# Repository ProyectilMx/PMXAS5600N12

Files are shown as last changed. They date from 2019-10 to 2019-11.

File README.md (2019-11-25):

PMXAS5600N12
Encoder Absoluto basado en el integrado AS5600 con 12 neopixels, configurable a través 
de COM Serial 9600 baudios

PMXAS5600N12 version 1.0 - 25/11/2019
PROYECTIL MX - HAZLO REAL

Modulo de Medicion Angular Absoluta Magnetica, programable mediante comandos UART

Esta provisto de un sensor de la marca AMS, el AS5600, que es un sensor
magnetico rotatorio de posicion con una resolucion de 12 bits, para un
rango por hardware de 4095°, el programa provee de otros 4095° para un
rango maximo total de -4095 a 4095°. Por defecto, el sitema viene en un
rango de 0 a 360°.

La placa contiene un microcontrolador maestro, basado en un ATSAMD21E18
de 32 bits, para realizar todas las mediciones y calculos a una velocidad 
de 96MHz, con este rapido sistema se logran obtener mediciones de hasta
6000RPM con 100% de presicion, tanto en revoluciones como en angulo.
La placa tambien consta de varios pines de salida para obtener funcionalidades
diversas:

PA27 - PA18:
Salidas programables en rangos angulares, programables en nivel alto o
bajo dentro de los mismos. Por defecto vienen con los siguientes limites:
PA27 -> de 0° a 90°
PA22 -> de 90° a 180°
PA19 -> de 180° a 270°
PA18 -> de 270° a 360°.
Con estas salidas se puede emular un registro de corrimiento de 4 bits o
activar subsistemas dentro de cierto angulo.

PA14, PA09:
Salidas que generan un pulso de 10us con cada revolucion. 
PA14 -> genera un pulso en el sentido de las manecillas del reloj. 
PA09 -> genera un pulso en el sentido contrario a las manecillas del reloj.

PA05:
Genera una señal PWM con una frecuencia variable entre 1 KHz y 4MHz, con un
ciclo de trabajo configurable entre 0 - 100%, dependiendo de la posicion angular.

PA02:
Genera una señal analogica de 10 bits, de entre 0 y 3.3v aproximadamente, 
dependiendo de la posicion angular.

PA07:
Se puede configurar para activarse dentro de un rango determinado de vueltas. 
Por ejemplo, si se configura que PA07 este en HIGH cuando se este entre 
0 y 500 vueltas, el pulso cambiara a LOW si el numero de vueltas esta fuera 
de ese intervalo.

PA06:
Se puede configurar para que al llegar a un multiplo de vueltas, por ejemplo, 15,  se de 
un pulso de un tiempo configurable en HIGH, por lo tanto este pulso sucederia en 0, 15,
30, 45, 60, 75.... vueltas.

PA04, PA03, PA01, PA00.
Salidas/Entradas: 
Estos pines solamente pueden ser entradas o salidas digitales.

Las funciones de la placa que se encuentran disponibles para el usuraio son:

void pmxas5600n12_configure(void);    - Configura todos los perifericos de la placa
void pmxas5600n12_exe(void);          - Ejecuta todas las acciones de control pertinentes a la placa

Se pueden utilizar las siguiente variables en el programa principal para interactuar con la placa:
 
user_turn       -  Reporta el numero de vueltas actual
user_angle      -  Reporta el angulo actual en 12 bits (0 - 4095)

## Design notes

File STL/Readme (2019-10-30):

Estos archivos son para imprimir en 3D un Knob compatible con la placa, el cual albergará un Imán de neodimio de 7mm de diámetro, por 3mm de espesor.

Es importante que el imán quede con los campos magnéticos perpendiculades a la placa, puesto que si queda alineado con ella, al rotar el imán, en realidad los campos seguirían estando igualemente orientados.

Knob-base.STL
Esta es la base atornillable a la PCB, por medio de 2 tornillos M3x6mm. Cuenta con espacio para un balero 624ZZ en su interior, comunmente utilizados para armar impresoras 3D.

Knob-giratorio.STL
Esta pieza alberga el imán de neodimio y cuenta con la forma para motar una neumático de llanta tipo Pololu de 30mm de diámetro.

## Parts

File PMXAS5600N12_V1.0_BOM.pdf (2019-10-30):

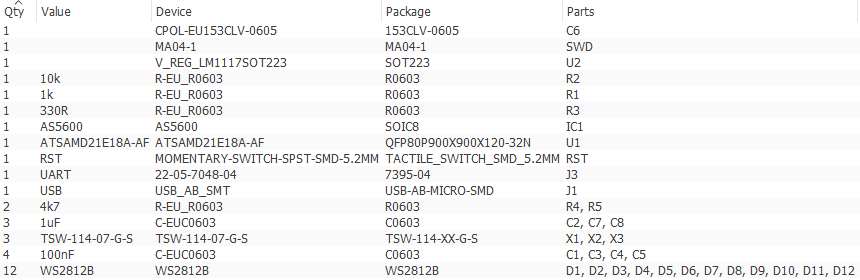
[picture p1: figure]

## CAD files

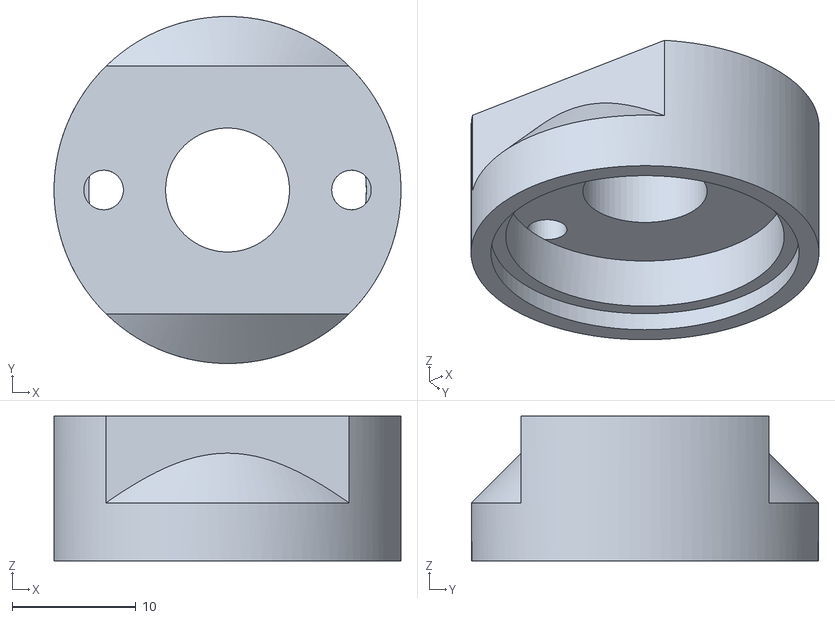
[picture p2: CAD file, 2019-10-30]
STL/Knob-base.stl
28.0 x 28.0 x 11.7

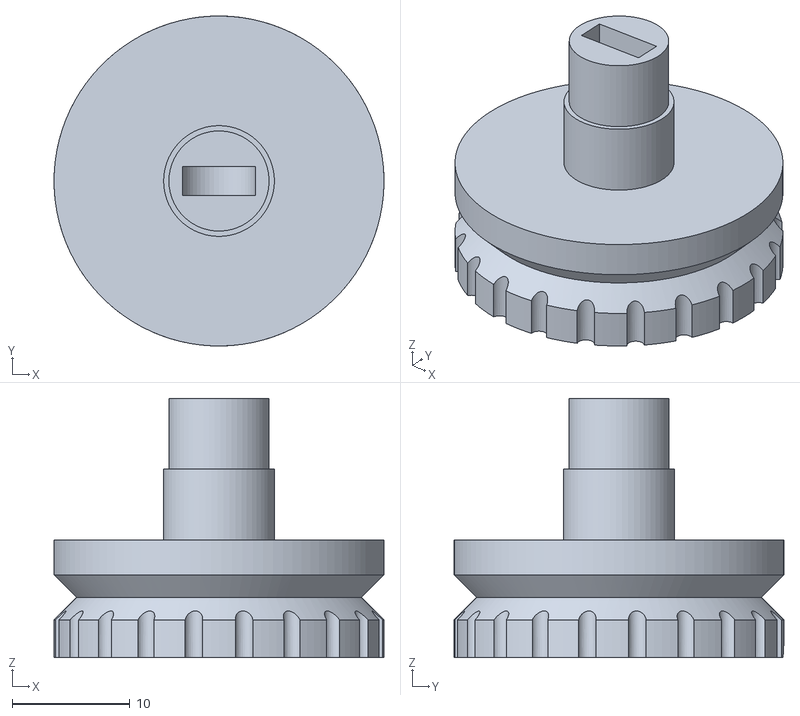
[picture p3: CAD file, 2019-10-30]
STL/Knob-giratorio.stl
28.0 x 28.0 x 22.0

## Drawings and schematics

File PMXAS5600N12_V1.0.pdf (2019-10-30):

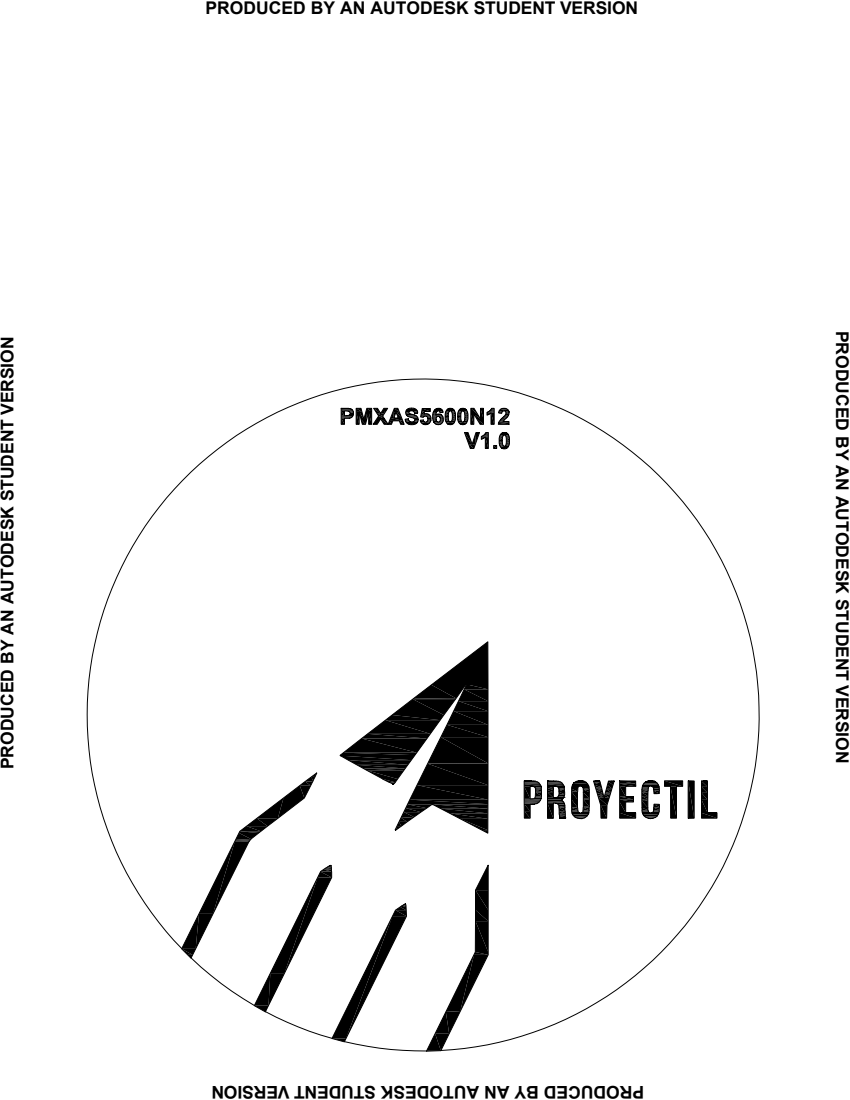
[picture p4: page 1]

PRODUCED BY AN AUTODESK STUDENT VERSION

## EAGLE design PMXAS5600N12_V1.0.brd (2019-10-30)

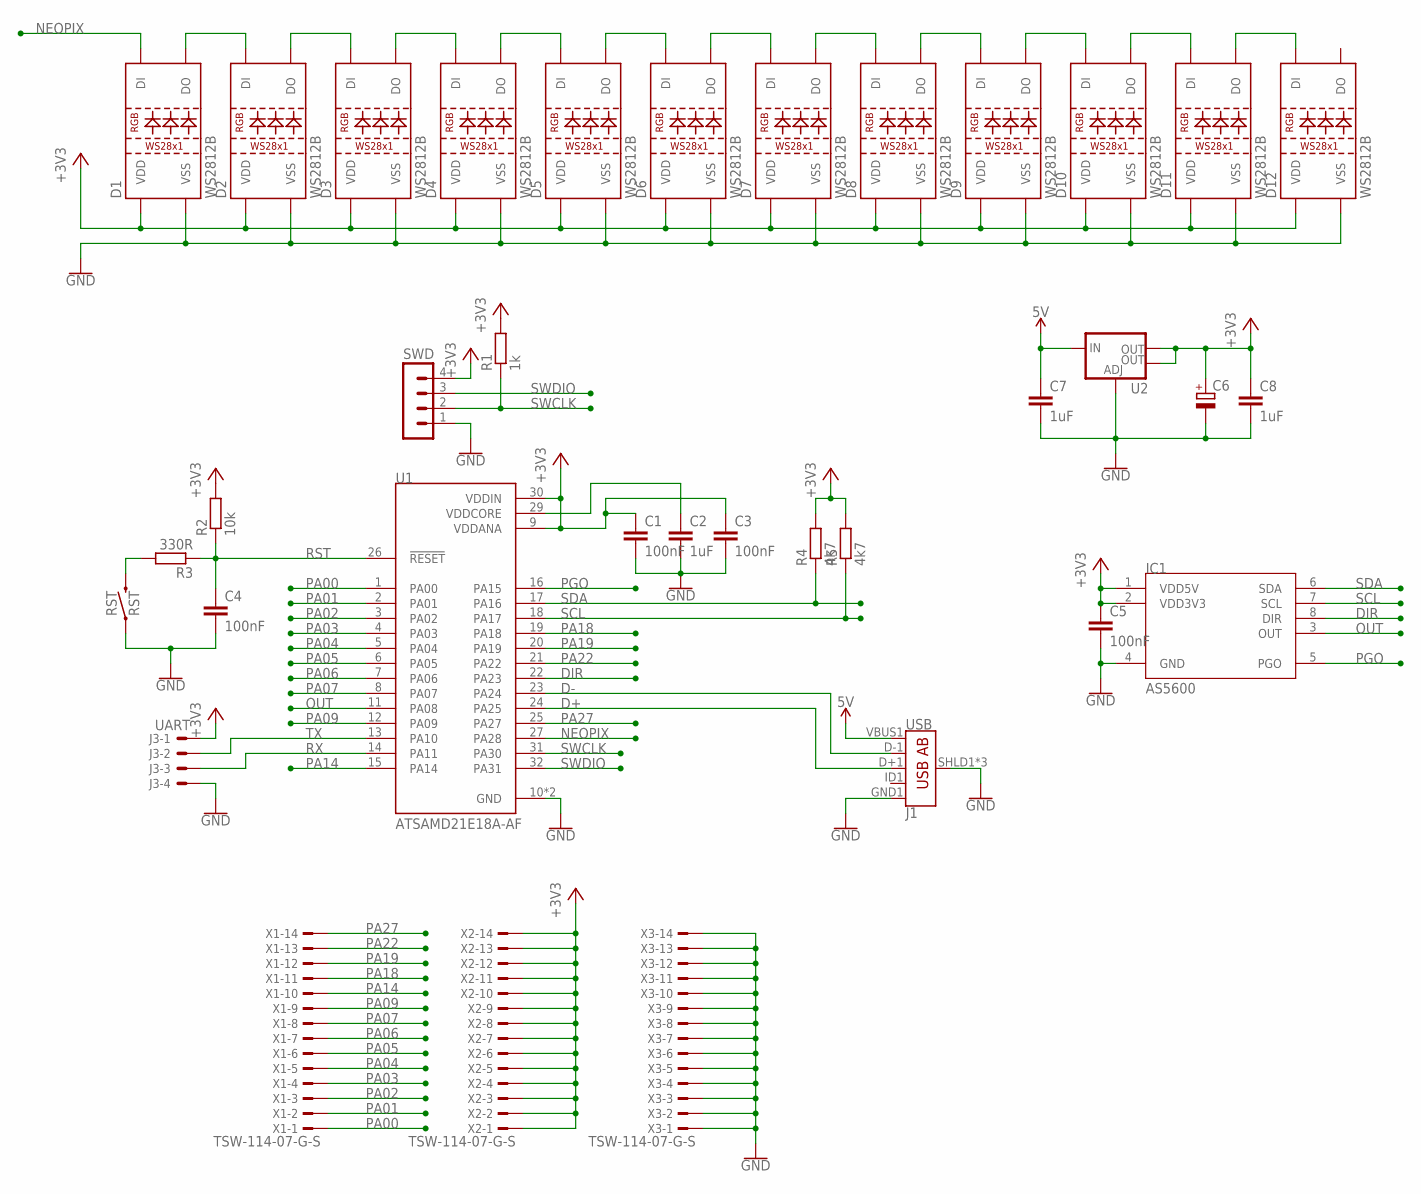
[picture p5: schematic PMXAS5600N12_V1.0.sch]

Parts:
C1, C3, C4, C5: 100nF; C0603
C2, C7, C8: 1uF; C0603
C6: CPOL-EU153CLV-0605; 153CLV-0605
D1, D2, D3, D4, D5, D6, D7, D8, D9, D10, D11, D12: WS2812B
IC1: AS5600; SOIC8
J1: USB; USB-AB-MICRO-SMD
J3: UART; 7395-04
R1: 1k; R0603
R2: 10k; R0603
R3: 330R; R0603
R4, R5: 4k7; R0603
RST: RST; TACTILE_SWITCH_SMD_5.2MM
SWD: MA04-1
U1: ATSAMD21E18A-AF; QFP80P900X900X120-32N
U2: V_REG_LM1117SOT223; SOT223
X1, X2, X3: TSW-114-07-G-S; TSW-114-XX-G-S

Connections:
5V: C7.1, J1.VBUS1 (VBUS), U2.3 (IN)
+3V3: C1.1, C3.1, C5.1, C6.+, C8.1, D1.1 (VDD), D2.1 (VDD), D3.1 (VDD), D4.1 (VDD), D5.1 (VDD), D6.1 (VDD), D7.1 (VDD), D8.1 (VDD), D9.1 (VDD), D10.1 (VDD), D11.1 (VDD), D12.1 (VDD), IC1.1 (VDD5V), IC1.2 (VDD3V3), J3.1, R1.2, R2.2, R4.2, R5.2, SWD.4, U1.9 (VDDANA), U1.30 (VDDIN), U2.2 (OUT), U2.4 (OUT), X2.1, X2.2, X2.3, X2.4, X2.5, X2.6, X2.7, X2.8, X2.9, X2.10, X2.11, X2.12, X2.13, X2.14
D+: J1.D+1 (D+), U1.24 (PA25)
D-: J1.D-1 (D-), U1.23 (PA24)
DIR: IC1.8 (DIR), U1.22 (PA23)
GND: C1.2, C2.2, C3.2, C4.2, C5.2, C6.-, C7.2, C8.2, D1.3 (VSS), D2.3 (VSS), D3.3 (VSS), D4.3 (VSS), D5.3 (VSS), D6.3 (VSS), D7.3 (VSS), D8.3 (VSS), D9.3 (VSS), D10.3 (VSS), D11.3 (VSS), D12.3 (VSS), IC1.4 (GND), J1.GND1 (GND), J1.SHLD1 (SHIELD), J1.SHLD2 (SHIELD), J1.SHLD3 (SHIELD), J3.4, RST.1, SWD.1, U1.10 (GND), U1.28 (GND), U2.1 (ADJ), X3.1, X3.2, X3.3, X3.4, X3.5, X3.6, X3.7, X3.8, X3.9, X3.10, X3.11, X3.12, X3.13, X3.14
unnamed: D1.2 (DO), D2.4 (DI)
unnamed: D2.2 (DO), D3.4 (DI)
unnamed: D3.2 (DO), D4.4 (DI)
unnamed: D4.2 (DO), D5.4 (DI)
unnamed: D5.2 (DO), D6.4 (DI)
unnamed: D6.2 (DO), D7.4 (DI)
unnamed: D7.2 (DO), D8.4 (DI)
unnamed: D8.2 (DO), D9.4 (DI)
unnamed: D9.2 (DO), D10.4 (DI)
unnamed: D10.2 (DO), D11.4 (DI)
unnamed: D11.2 (DO), D12.4 (DI)
unnamed: R3.2, RST.3 (2)
NEOPIX: D1.4 (DI), U1.27 (PA28)
OUT: IC1.3 (OUT), U1.11 (PA08)
PA00: U1.1 (PA00), X1.1
PA01: U1.2 (PA01), X1.2
PA02: U1.3 (PA02), X1.3
PA03: U1.4 (PA03), X1.4
PA04: U1.5 (PA04), X1.5
PA05: U1.6 (PA05), X1.6
PA06: U1.7 (PA06), X1.7
PA07: U1.8 (PA07), X1.8
PA09: U1.12 (PA09), X1.9
PA14: U1.15 (PA14), X1.10
PA18: U1.19 (PA18), X1.11
PA19: U1.20 (PA19), X1.12
PA22: U1.21 (PA22), X1.13
PA27: U1.25 (PA27), X1.14
PGO: IC1.5 (PGO), U1.16 (PA15)
RST: C4.1, R2.1, R3.1, U1.26 (!RESET)
RX: J3.3, U1.14 (PA11)
SCL: IC1.7 (SCL), R5.1, U1.18 (PA17)
SDA: IC1.6 (SDA), R4.1, U1.17 (PA16)
SWCLK: R1.1, SWD.2, U1.31 (PA30)
SWDIO: SWD.3, U1.32 (PA31)
TX: J3.2, U1.13 (PA10)
VDDCORE: C2.1, U1.29 (VDDCORE)

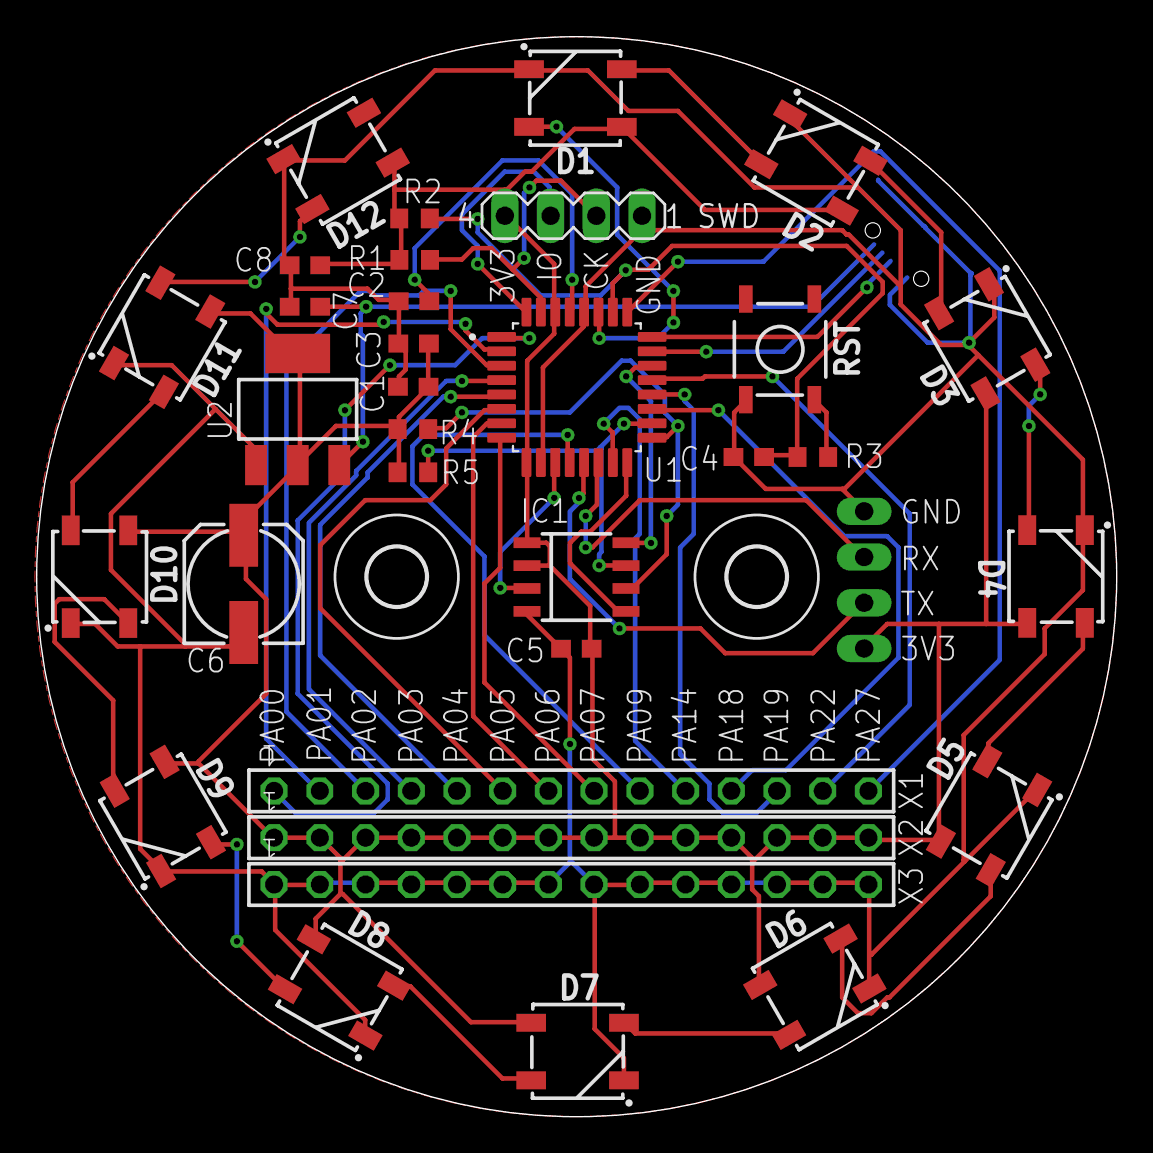
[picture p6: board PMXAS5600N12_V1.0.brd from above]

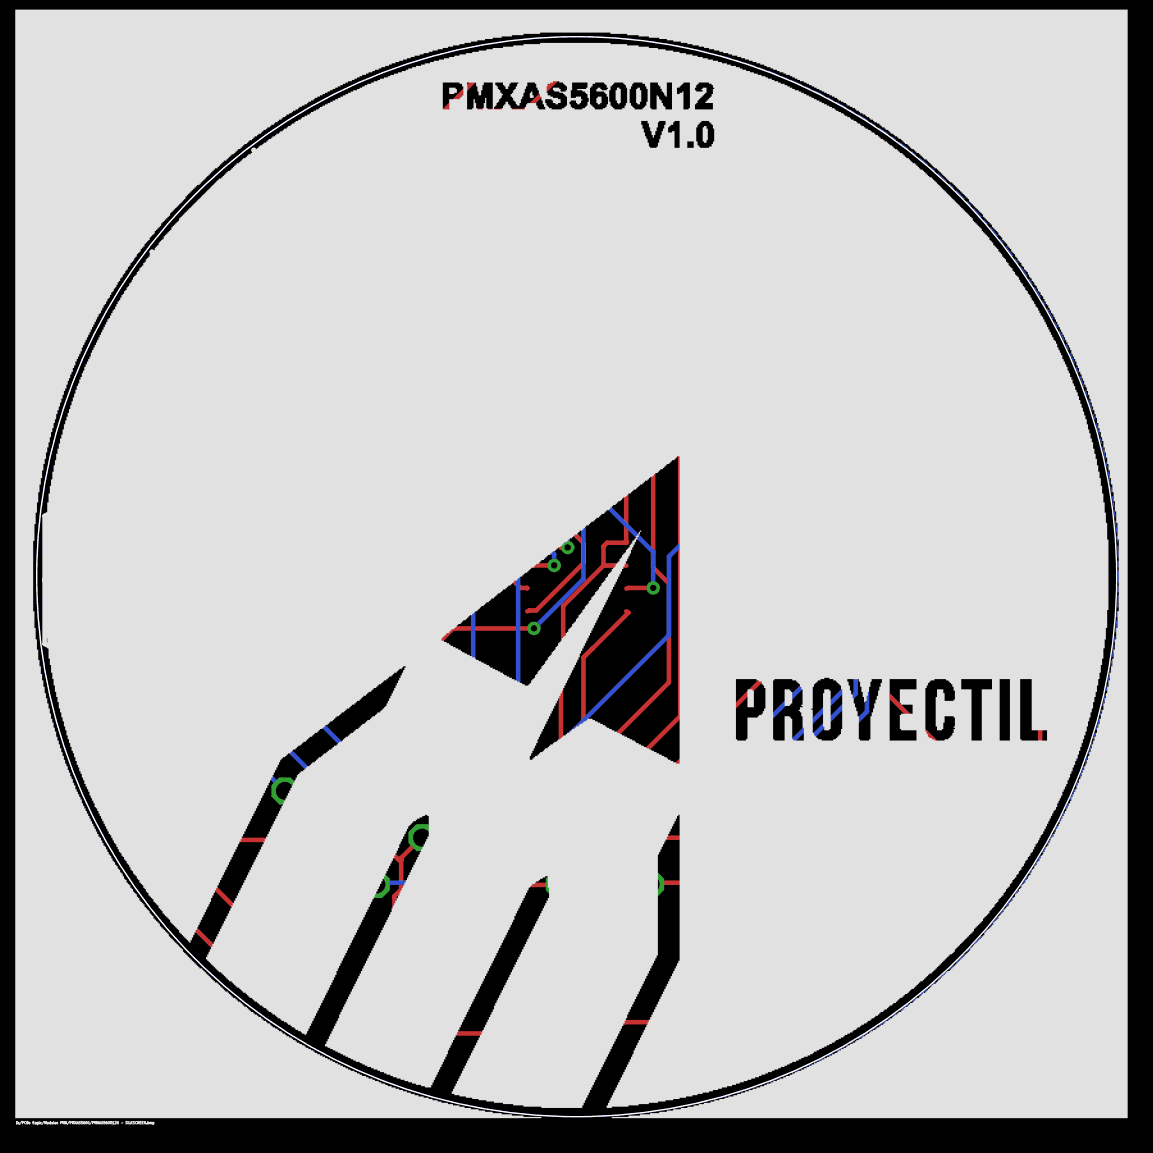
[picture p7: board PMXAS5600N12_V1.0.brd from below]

Board: 2 copper layers, 60.0 x 60.0 mm, 37 parts (2 on the bottom side), 43 nets.

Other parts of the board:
U$1, U$2: 3,2

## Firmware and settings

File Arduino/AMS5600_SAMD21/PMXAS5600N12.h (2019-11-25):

#include <Arduino.h>         
#include <Wire.h>
#include <AMS_5600.h> 
#include <stdio.h>
#include <string.h>
#include <ctype.h>
#include <FlashStorage.h>
#include <Adafruit_NeoPixel.h>

#define NEOP      9   // pin de neopixel
#define PIX_NUM   12  // numero de neopixels
// Crea instancia e inicializa Neopixels
Adafruit_NeoPixel pixels = Adafruit_NeoPixel(PIX_NUM, NEOP, NEO_GRB + NEO_KHZ800);

// Crea instancia para el sensor
AMS_5600 ams;

#define OSC_FREQ        48000000
#define I2CSPEED        1000000

#define USB             1
#define SERIAL          0

#define ONE_THIRD_FULL_ANGLE    1365
#define TWO_THIRD_FULL_ANGLE    2730
#define PIX_PORTION     342
#define CCW             0
#define CW              1
#define NO_ACK          0
#define MIN_ACK         1
#define FULL_ACK        2
#define CALL            0
#define CHANGE          1
#define FLUID           2
#define DUTY            0
#define FREQUENCY       1  

#define VERSION         1
#define ANGLEMAX        2
#define ANGLEMIN        3
#define ANGLEFULL       4
#define ANGLE           5
#define DIRECTION       6
#define TURN            7
#define PA27MIN_ANGLE   8
#define PA27MAX_ANGLE   9
#define PA22MIN_ANGLE   10
#define PA22MAX_ANGLE   11
#define PA19MIN_ANGLE   12
#define PA19MAX_ANGLE   13
#define PA18MIN_ANGLE   14
#define PA18MAX_ANGLE   15
#define PA07MIN_TURN    16
#define PA07MAX_TURN    17
#define PA06MULTIPLE    18
#define BAUD            19

#define RED             1
#define GREEN           2
#define BLUE            3
#define YELLOW          4
#define MAGENTA         5
#define CYAN            6
#define WHITE           7

#define SINGLE          1
#define RISING          2
#define FALLING         3

FlashStorage(ADD_ack_level, int);
FlashStorage(ADD_flag_angleFluid, short);
FlashStorage(ADD_flag_turnFluid, short);
FlashStorage(ADD_updateMode, short);
FlashStorage(ADD_max_angle, int);
FlashStorage(ADD_min_angle, int);
FlashStorage(ADD_turn, long long);
FlashStorage(ADD_turnUpdate, short);
FlashStorage(ADD_direction, short);
FlashStorage(ADD_angleContinue, short);
FlashStorage(ADD_angleUpdate, short);
FlashStorage(ADD_turnContinue, short);
FlashStorage(ADD_pa27_min_angle, int);
FlashStorage(ADD_pa27_max_angle, int);
FlashStorage(ADD_pa27_enable, int);
FlashStorage(ADD_pa27_logic, short);
FlashStorage(ADD_pa22_min_angle, int);
FlashStorage(ADD_pa22_max_angle, int);
FlashStorage(ADD_pa22_enable, int);
FlashStorage(ADD_pa22_logic, short);
FlashStorage(ADD_pa19_min_angle, int);
FlashStorage(ADD_pa19_max_angle, int);
FlashStorage(ADD_pa19_enable, int);
FlashStorage(ADD_pa19_logic, short);
FlashStorage(ADD_pa18_min_angle, int);
FlashStorage(ADD_pa18_max_angle, int);
FlashStorage(ADD_pa18_enable, int);
FlashStorage(ADD_pa18_logic, short);
FlashStorage(ADD_pa07_min_turn, int);
FlashStorage(ADD_pa07_max_turn, int);
FlashStorage(ADD_pa07_enable, int);
FlashStorage(ADD_pa07_logic, short);
FlashStorage(ADD_pa06_turn_mult, int);
FlashStorage(ADD_pa06_enable, int);
FlashStorage(ADD_pa06_logic, short);
FlashStorage(ADD_pa06_pulse_duration, int);

FlashStorage(ADD_baud, long);
FlashStorage(ADD_ackDelay, unsigned int);
FlashStorage(ADD_color_bright, unsigned int);
FlashStorage(ADD_pixel_enable, short);
FlashStorage(ADD_pixel_color, int);
FlashStorage(ADD_pixel_effect, int);
FlashStorage(ADD_turn_pulse_duration, int);

// Variables globales
bool input_channel;
int max_angle = 360;
int min_angle = 0;
const long long min_turn = -2147483648;
const long long max_turn = 2147483647;
int full_angle = max_angle - min_angle;
int ack_level = FULL_ACK;
int raw_angle;
int angle;
int raw_new_angle;
int new_angle;
int user_angle;
int user_turn;
int raw_old_angle;
int old_angle;
int ackDelay = 1000;
int requestValue = NULL;
int color_bright = 50;
int pixel_color = RED;
int pixel_effect = SINGLE;
int turn_pulse_duration = 1000;   // uS
int pa27_min_angle = 0;
int pa27_max_angle = 90;
int pa22_min_angle = 90;
int pa22_max_angle = 180;
int pa19_min_angle = 180;
int pa19_max_angle = 270;
int pa18_min_angle = 270;
int pa18_max_angle = 360;
int pa07_min_turn = 0;
int pa07_max_turn = 10;
int pa06_pulse_duration = 100;    // uS
long long pa06_turn_mult = 10;  // multiplo de vueltas para dar un pulso en PA06
int updateMode = CALL;
int ind[5] = {0,0,0,0,0}; // posiciones de los comandos

long baud = 9600;
long long turn = 0;
long long new_turn;
long long old_turn;

short flag_newCommand = false;
short flag_newTurn = false;
short flag_turnChanged = false;
short flag_angleFluid = true;
short flag_angleChanged = false;
short flag_turnFluid = true;
short flag_direction = CW;
short flag_error_syntax = false;
short flag_error_range = false;
short flag_error_void = false;
short flag_pa27_level = HIGH;
short flag_pa22_level = HIGH;
short flag_pa19_level = HIGH;
short flag_pa18_level = HIGH;
short flag_pa07_level = HIGH;
short flag_pa06_level = HIGH;
short pa27_enable = true;
short pa27_logic = true;
short pa22_enable = true;
short pa22_logic = true;
short pa19_enable = true;
short pa19_logic = true;
short pa18_enable = true;
short pa18_logic = true;
short pa07_enable = true;
short pa07_logic = true;
short pa06_enable = true;
short pa06_logic = true;
short pixel_enable = true;


String firmwareVersion = "PMXAS5600N12 - Version 1.0 - 28/02/2019";
String readString; // string introducido por usuario
String subCom[6] = {"","","","","",""}; // String para cada subcomando
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

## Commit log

2019-11-01 Add files via upload
    En esta carpeta se encuentran los archivos Variant para una configuración de Arduino más avanzada
    [PMXAS5600N12.cfg]
2019-11-25 Se lanza la versión publica de PMXAS5600N12
    - Se corrigieron algunos bugs
    - Se implementó nueva funcionalidad en los pines PA06 y PA07
    - Se bajó la velocidad por defecto a 9600 bauds.
    - Se habilitó el Serial1 para poder comunicarse con otra placa.
    [AMS5600_SAMD21.ino, PMXAS5600N12.h]
2019-11-25 Actializacion de Readme con nuevas funciones
2019-11-25 Corrección de errores Ortográficos
2019-11-25 Cambios en la descripción de la placa PMXAS5600N12
2019-11-25 Cambio de caracteres de separación y termino
    Otros Cambios menores

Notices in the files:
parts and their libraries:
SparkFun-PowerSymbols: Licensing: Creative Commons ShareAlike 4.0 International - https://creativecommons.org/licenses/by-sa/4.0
